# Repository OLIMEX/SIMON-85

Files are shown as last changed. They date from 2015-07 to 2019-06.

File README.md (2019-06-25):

# SIMON-85

## About
The board is an implementaion of the popular simon game which tests and trains your short-term memory. There are four LEDs, four buttons and a buzzer. The LEDs blink in random pattern which you should repeat with the buttons. Each successful guess makes the buzzer produce a sound. Each successful guess increments the amount of blinks, thus the difficulty.

The only hardware requirement for the typical use of the board is:
* USB type A to USB mini cable – to connect to a personal computer; it is used for powering the board and uploading new programs via Arduino

The board can be programmed with Digispark's Arduino distributions. Link to the download page of Digispark's Arduino distributions, suitable for Windows, Linux and MacOS: http://digistump.com/wiki/digispark/tutorials/connecting

The initial bootloader firmware can be uploaded with any combination of third party programming tool and programming software that are compatible with ATTiny85.

The binaries are suitable only for SIMON-85 board.

## How to upload binaries:

### AVR/Atmel studio
Use AVR/Atmel Studio or AVRDude to upload respectivley the .elf or the .hex to the target ATtiny85.
The .elf file contains the proper fuses and configuration bits. If you use the .hex you would need to set the fuses manually.

***It is always recommended to use the latest .hex or the latest .elf!***

## avrdude
If you use AVRDude then you need to pass the fuse settings as command line:

    avrdude -c avrispmkII -p attiny85 -U lfuse:w:0xE1:m -U hfuse:w:0xDD:m -U efuse:w:0xFE:m

If you use another programmer change ***avrispmkII*** e.g. ****stk500v2****:

    avrdude -c stk500v2 -P com26 -p attiny85 -U flash:w:<latest_version>.hex -U lfuse:w:0xE1:m -U hfuse:w:0xDD:m -U efuse:w:0xFE:m

## About the ATtiny85 fuses

Fuse name  |HEX value|Description
-----------|---------|-----------
EXTENDED|0xFE|SELFPROGEN - checked
HIGH|0xDD|Brown-out detection at VCC=2.7 V; the rest of the fuses unchecked
LOW|0xE1|PLL Clock; Start-up time PWRDWN/RESET: 1K CK/14 CK + 64 ms

The core design of the board is similar to the design of the previously released OLinuXino-85 and FOSDEM-85 boards. This might be helpful in your attempt to implementing additional examples.

THE DESIGN OF SIMON-85 IS BASED HEAVILY ON THE LITTLE WIRE'S DESIGN BY IHSAN KEHRIBAR AND USES MICRONUCLEUS BOOTLOADER AND DIGISTUMP'S DIGISPARK SOFTWARE. SIMON-85 WOULD NOT HAVE BEEN POSSIBLE WITHOUT THE EXISTENCE OF THESE PROJECTS.

The board is completely open software and open hardware.

Product pages:

* SIMON-85: https://www.olimex.com/Products/Duino/AVR/SIMON-85/open-source-hardware
* SIMON-85-KIT (DIY kit): https://www.olimex.com/Products/Duino/AVR/SIMON-85-KIT/open-source-hardware

## LICENSE
* Software License is GPL3
* Hardware License is Apache 2.0
* Documentation License is CC-BY-SA3.0 (https://creativecommons.org/licenses/by-sa/3.0/)

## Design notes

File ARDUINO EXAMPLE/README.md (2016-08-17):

## Simon-85 example description

The board is an implementation of the popular simon game which tests and trains your short-term memory.
There are four LEDs and four buttons. The LEDs blink in random pattern which you should repeat with the buttons.
Each successful guess increments the amount of blinks.

There are 4 levels of difficulties that can be selected.

### To select the level
After the board has been powered on (be patient, there is definite timeout) and the four leds are blinking consecutively, you must press and hold any button from BUT1 to BUT4. The number of the button corresponds directly to the level's number.

***That's all! Enjoy the game!***

SIMON-85 is built around the well-known Little wire design. The same design is also used for the Digispark and Adafruit’s Trinket. The microcontroller comes preprogrammed with "micronucleus tiny85" that is suitable for use with the Digispark's Arduino distribution.

## Simon-85 example installation

### Hardware and software prerequisites:

#### Hardware
* 1x Simon-85
* 1x cable to connect the board and your PC
* 1x properly installed Digispark Arduino IDE with installed AVR Digistump board package

#### Software
 * The example library is archived as zip. Please extract it anywhere and point the IDE to the .ino file inside the "Simon" folder with File -> Open

#### Notes!
* To upload the program you must first select BOTH "Tools → board" as "Digispark 8mhz - NO USB (Tiny Core)" and "Tools → Programmer" to "Digispark"
* You need to click "Upload" button first, wait for the program to compile and THEN plug the board - this is because the bootloader implementation runs for the first few seconds after power up and then the user program is executed. If you plug the board before programming the bootloader won't be available and uploading will fail. Disconnect the board, click "Upload" again and then connect the board.

There are detailed instructions in the manual and the digispark's wiki pages.

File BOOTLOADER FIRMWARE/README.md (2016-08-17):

# Bootloader binaries

The binaries consist of Digispark bootloader and Simon-85 demo example.
If you use .hex file please remember to burn fuses as well.

Current bootloader version: 2.03

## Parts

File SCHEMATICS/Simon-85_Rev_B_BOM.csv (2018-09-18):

Part | Value | Device | Package | Description
BAT-3.7V | DW02S | CON2DW02S | DW02S
BUT1 | DTSM24R(12x12x10) | SW-TAKTSS | SW_TAKT12X12SS
BUT2 | DTSM24R(12x12x10) | SW-TAKTSS | SW_TAKT12X12SS
BUT3 | DTSM24R(12x12x10) | SW-TAKTSS | SW_TAKT12X12SS
BUT4 | DTSM24R(12x12x10) | SW-TAKTSS | SW_TAKT12X12SS
BUZZER | PT1240 | BUZ3 | BUZ14MM
C1 | 10uF/16V/105C(5x11mm,RM2) | CPOL-EUE2-5_BOT | E2-5_B | POLARIZED CAPACITOR, European symbol
C2 | 100nF/2010 | C-EU025-025X050 | C025-025X050 | CAPACITOR, European symbol
C3 | 100nF/2010 | C-EU025-025X050 | C025-025X050 | CAPACITOR, European symbol
D1 | 1N4148/DO35 | DDO35 | DO35-200MILS | DIODES
D2 | 1N4148/DO35 | DDO35 | DO35-200MILS | DIODES
D3 | 1N4148/DO35 | DDO35 | DO35-200MILS | DIODES
D4 | 1N4148/DO35 | DDO35 | DO35-200MILS | DIODES
D5 | 1N4148/DO35 | DDO35 | DO35-200MILS | DIODES
LED1 | LED/Green/5mm | LED5.0MM | LED-5.0MM
LED2 | LED/Red/5mm | LED5.0MM | LED-5.0MM
LED3 | LED/White/5mm | LED5.0MM | LED-5.0MM
LED4 | LED/Blue/5mm | LED5.0MM | LED-5.0MM
R1 | 10k/0.25W | R-EU_0207/10 | 0207/10 | RESISTOR, European symbol
R2 | 3.9k/0.25W | R-EU_0207/10 | 0207/10 | RESISTOR, European symbol
R3 | 22R/0.25W | R-EU_0207/10 | 0207/10 | RESISTOR, European symbol
R4 | 22R/0.25W | R-EU_0207/10 | 0207/10 | RESISTOR, European symbol
R5 | 560R/0.25W | R-EU_0207/10 | 0207/10 | RESISTOR, European symbol
R6 | 2k/0.25W | R-EU_0207/10 | 0207/10 | RESISTOR, European symbol
R7 | 560R/0.25W | R-EU_0207/10 | 0207/10 | RESISTOR, European symbol
R8 | 560R/0.25W | R-EU_0207/10 | 0207/10 | RESISTOR, European symbol
R9 | 560R/0.25W | R-EU_0207/10 | 0207/10 | RESISTOR, European symbol
R10 | 560R/0.25W | R-EU_0207/10 | 0207/10 | RESISTOR, European symbol
R11 | 560R/0.25W | R-EU_0207/10 | 0207/10 | RESISTOR, European symbol
R12 | 560R/0.25W | R-EU_0207/10 | 0207/10 | RESISTOR, European symbol
U1 | ATtiny85-20PU+(DIL-8) | ATTINY85-20PU | DIP8 | Atmel 8-bit AVR Microcontroller with 2/4/8K Bytes In-System Programmable Flash
USB | USB-B | USB_SHIELD | USB_NEAR_BLACK

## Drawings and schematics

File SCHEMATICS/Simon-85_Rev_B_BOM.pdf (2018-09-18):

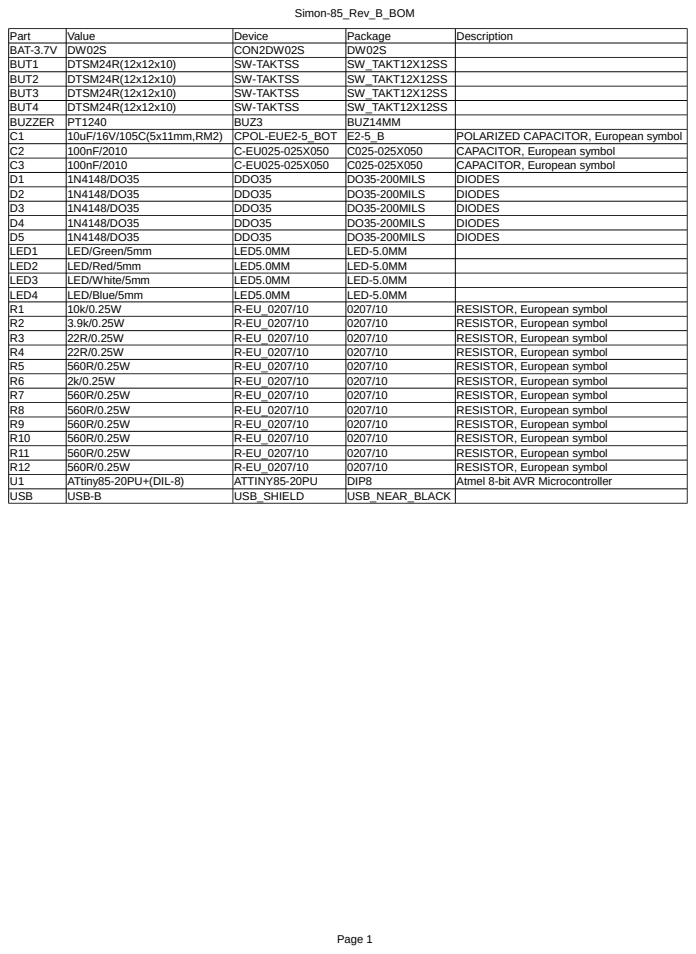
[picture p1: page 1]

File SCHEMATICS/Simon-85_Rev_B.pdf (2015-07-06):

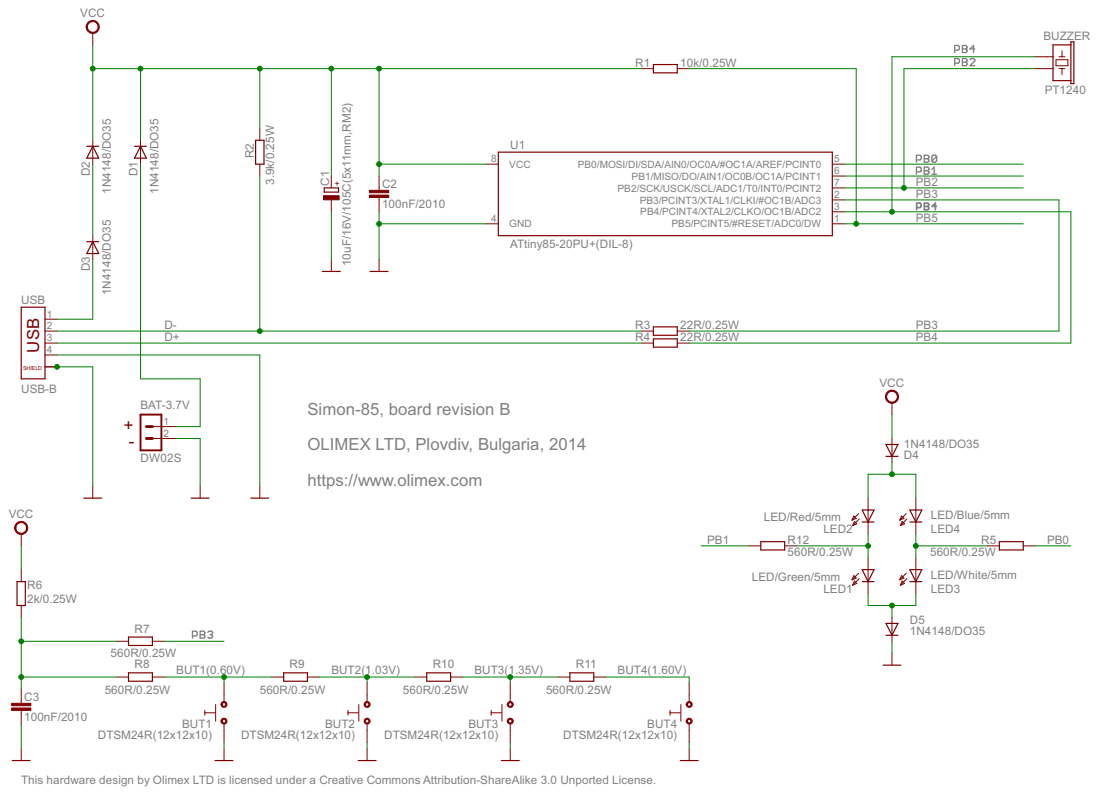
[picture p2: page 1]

6 PB0/MOSI/DI/SDA/AIN0/OC0A/#OC1A/AREF/PCINT0

OLIMEX LTD, Plovdiv, Bulgaria, 2014

https://www.olimex.com

This hardware design by Olimex LTD is licensed under a Creative Commons Attribution-ShareAlike 3.0 Unported License.

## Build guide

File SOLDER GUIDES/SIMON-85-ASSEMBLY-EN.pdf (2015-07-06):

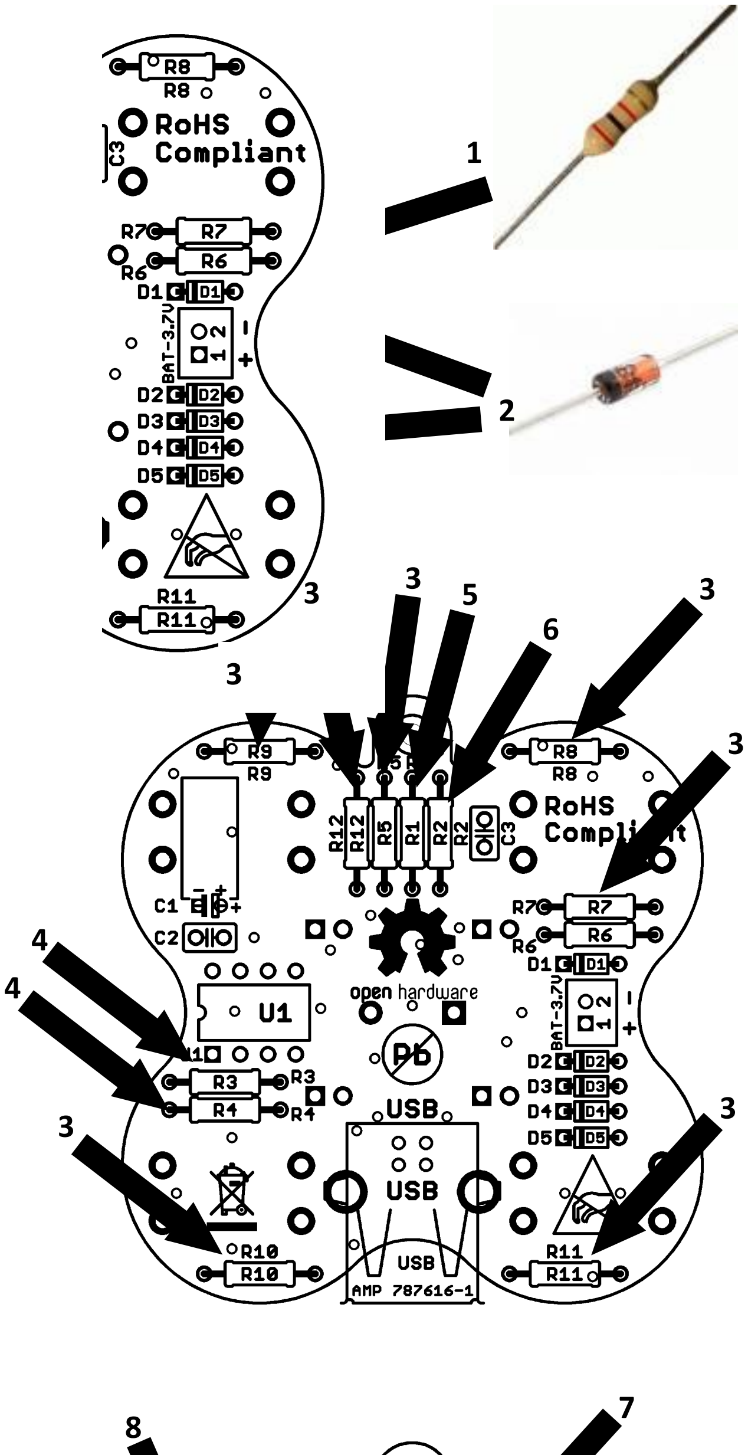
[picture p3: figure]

1. A 2K ohm resistor (red, black, red, golden) position R6.
2. 5 x Diodes 1N4148 positions D1, D2, D3, D4, and D5. Watch out for the orientation. The stripe of the diode has to be oriented as indicated by the white print on the board.
3. 7 x 560 ohm resistors (green, blue, brown, gold) at positions R5, R7, R8, R9, R10, R11, R12.
4. 2 x 22 ohm resistors (red, red, black, gold) at positions R3 and R4.
5. A 10k ohm resistor (brown, black, orange, gold) at position R1.
6. A 3.9K ohm resistor (orange, white, red, gold) at position R2.
7. 2 x capacitors 100nF (code 104) at positions C2 and C3.

### 8. An electrolytic capacitor 10μF at position C1. The

component has polarity! The short pin is negative (-), the long pin is positive (+). Place it in the holes and leave some space between the capacitor and the board. Bend the pins to lie horizontally (e.g. flat) on the board. Then proceed to solder it.

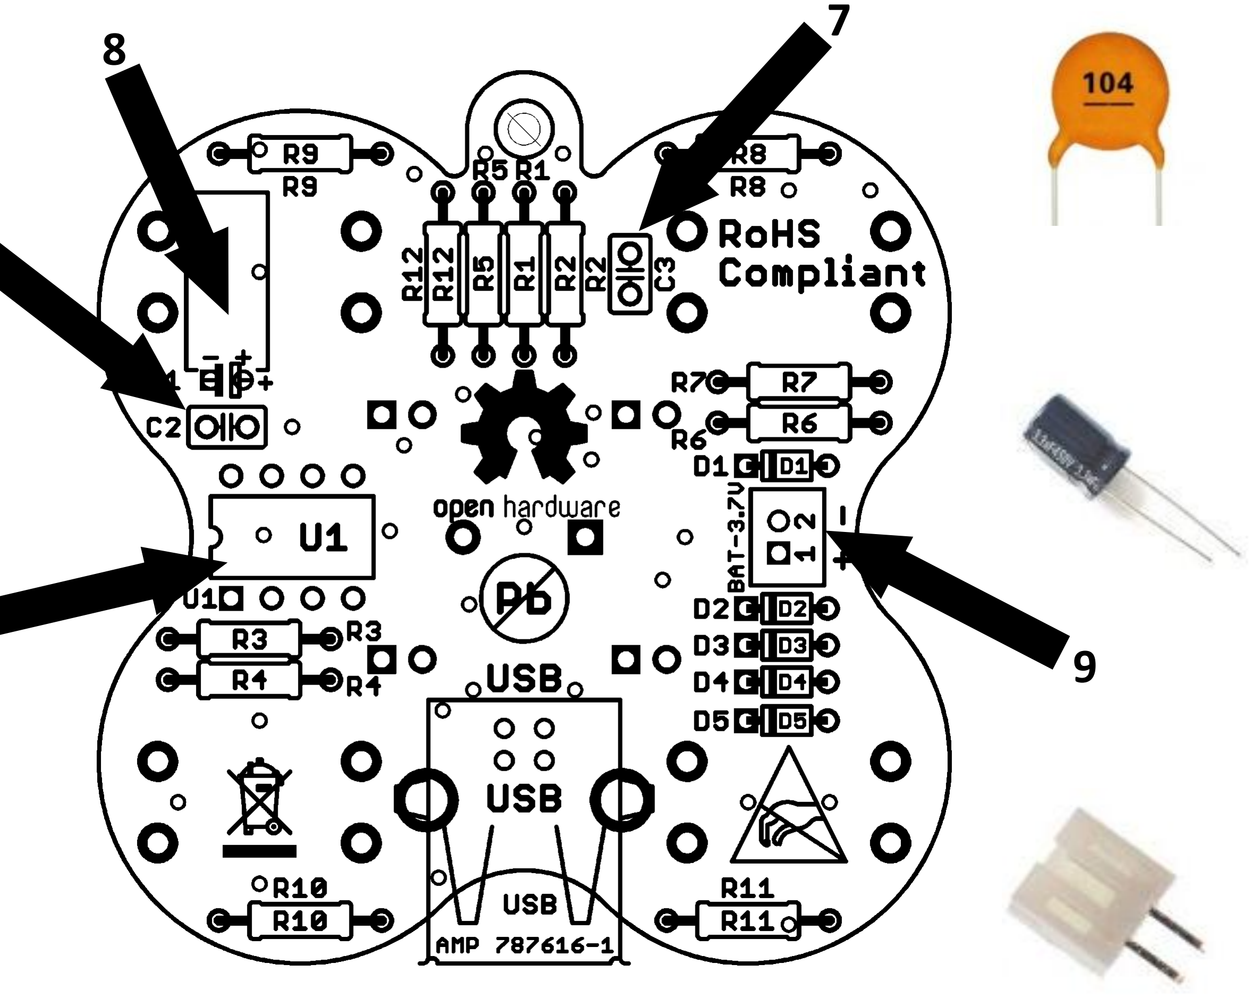
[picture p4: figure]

### 10. An 8-pin DIL socket at position U1. Be careful! The microcontroller may overheat

during prolonged soldering. It is recommended to remove the ATtiny85 from the socket before soldering. Watch out for the socket orientation! The socket has a dent that should be facing outwards of the board.

### 9. A connector DW02S. Be careful with the

orientation. The gap in the connector must be facing towards the middle of the board!

7

10

SIMON-85-KIT. Soldering details, order, and tips.

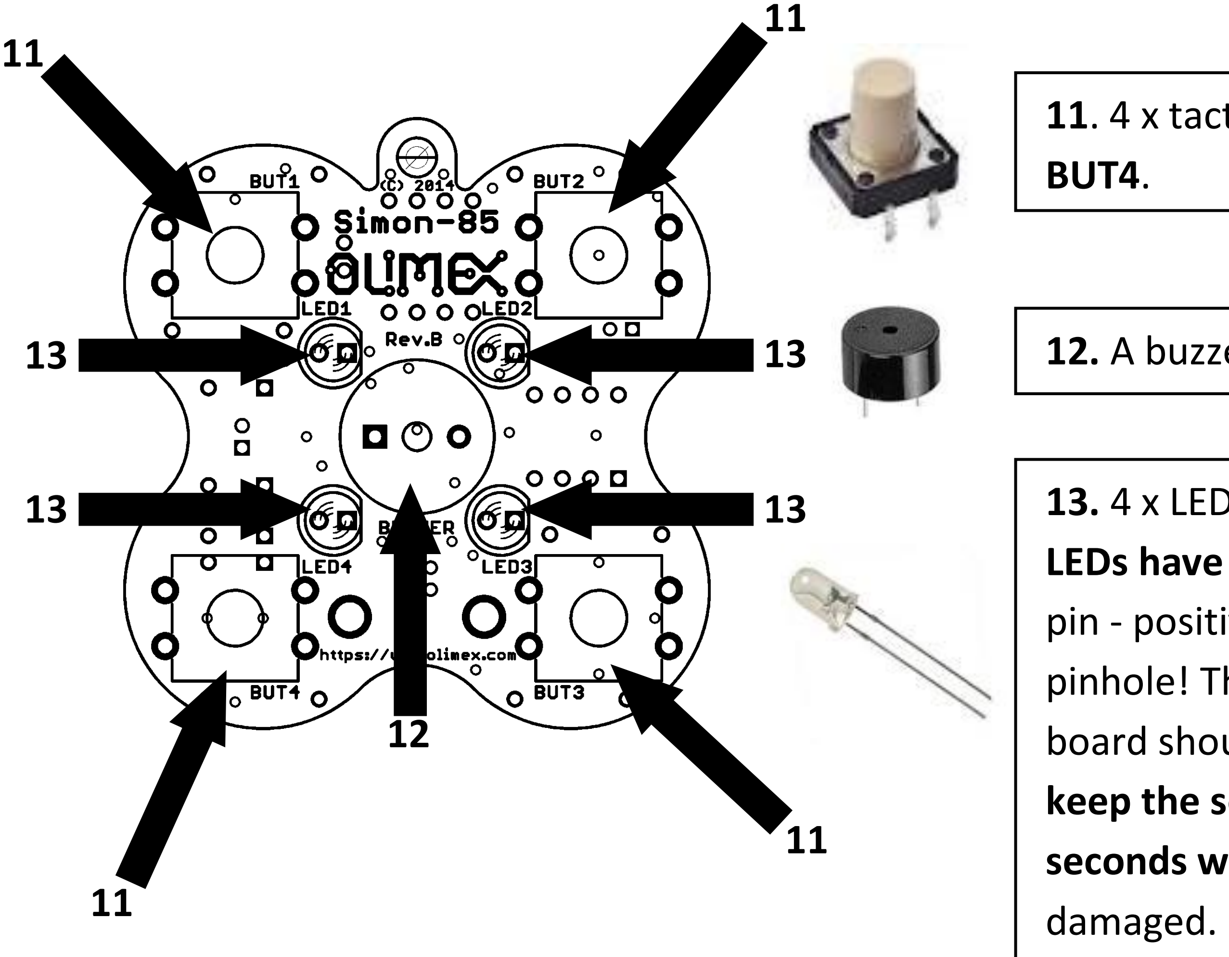
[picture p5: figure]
BUT4.; damaged.
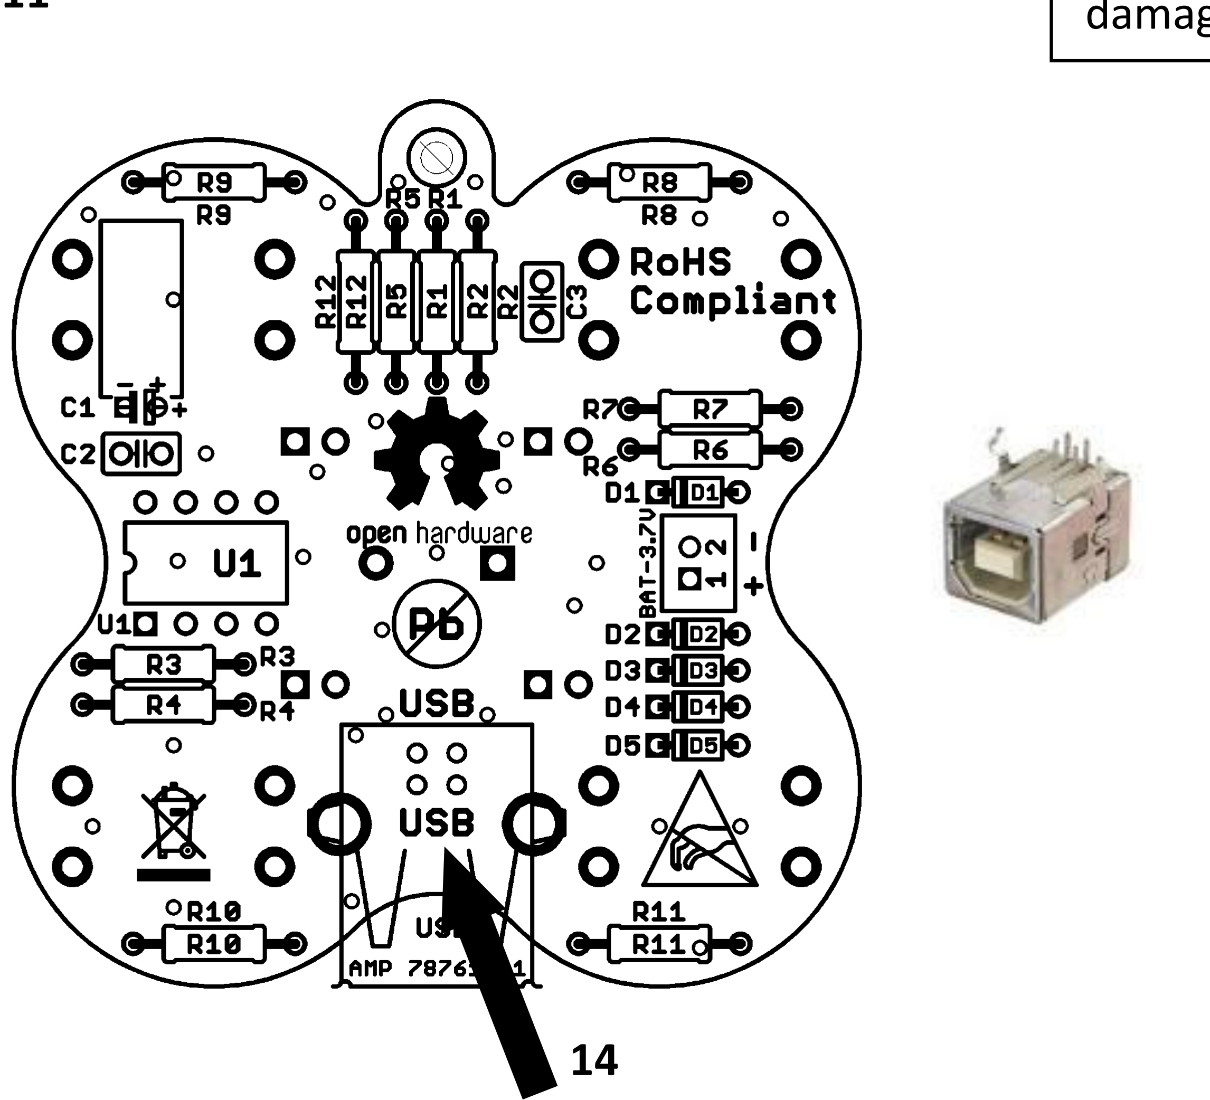
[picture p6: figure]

Turn the board and wait for about 5 seconds. Then four LEDs should turn on. Check the next page for game description and available difficulties!

11. 4 x tactile buttons at positions BUT1, BUT2, BUT3, and
13. 4 x LEDs at positions LED1, LED2, LED3, and LED4. LEDs have polarity! The short pin is negative (-), the long pin - positive (+). The negative pin goes to the square pinhole! The flat line vsible on the white print of the board should match the flat side of the diode. Do not keep the soldering iron pressed for more than 2-3 seconds when soldering. Else the LED might get

### 14. A USB type B connector at position USB. The

connector is placed at the same side of the board as the microcontroller! Double check for short-circuits between the pins before powering!

12. A buzzer at position BUZZER.

### 15. After successful assembly of all other components – place the ATtiny85

microcontroller in the U1 DIL-8 socket. Be careful with the orientation. The microcontroller has a dot, which indicates the first pin. The dot should be facing outwards the board.

=== SIMON-85 default game description ===

The board is an implementation of the popular simon game which tests and trains your short-term memory.

The board gets powered by a USB cable compatible with the board’s USB type B connector. You need to wait at least 5 seconds after the board gets powered.

There are four LEDs and four buttons. A number of LEDs blink in a random pattern which you should repeat with the buttons. Each successful guess increments the amount of blinks that you would need to guess. If you make an erroneous button press the game would restart.

The buzzer sounds would help you remember the patterns. There is a victory song If manage to complete the game.

There are 4 levels of difficulties that can be selected.

Level 1 -> 10 repetitions

Level 2 -> 20 repetitions

Level 3 -> 30 repetitions

Level 4 -> 40 repetitions

To select the difficulty level: after the board had been powered on (be patient, there is timeout defined on purpose) and the four leds are blinking consecutively, you must press and hold any button from BUT1 to BUT4. The number of the button corresponds directly to the level's number.

That's all! Enjoy the game!

For additional resources (sources and schematics) please visit the products web-page at Olimex web-site:

https://www.olimex.com/Products/Duino/AVR/SIMON-85-KIT

The board is also available in a ready-to-use and soldered variant. For more information please visit the product’s web-page at our web-site:

https://www.olimex.com/Products/Duino/AVR/SIMON-85

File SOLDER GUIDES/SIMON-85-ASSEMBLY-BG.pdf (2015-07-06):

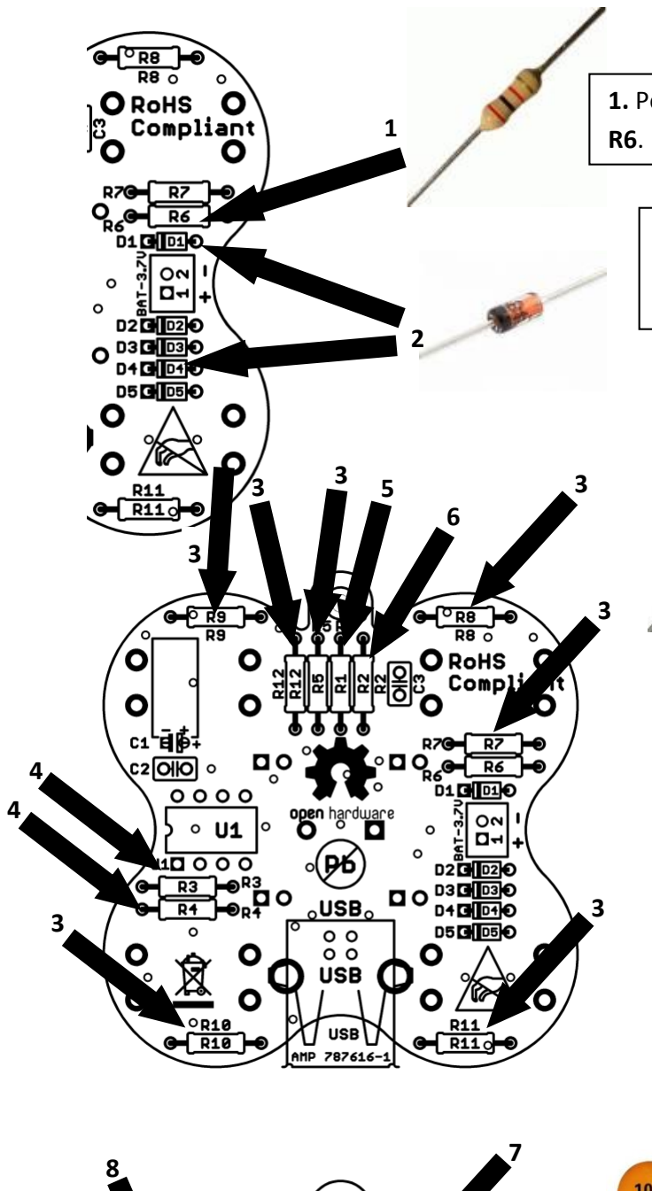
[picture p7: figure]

### 1. Резистор 2K ома (червено, черно, червено, златно) на позиция

2. Диод 1N4148 на позиции D1, D2, D3, D4 и D5. Внимавайте за ориентацията. Чертата на диода трябва да е с еднаква посока като тази на печата на платката.
3. Резистор 560 ома (зелено, синьо, кафяво, златно) на позиции R5, R7, R8, R9, R10, R11, R12.
4. Резистор 22 ома (червено, червено, черно, златно) на позиции R3 и R4.
5. Резистор 10k ома (кафяво, черно, оранжево, златно) на позиция R1.
6. Резистор 3,9k ома (оранжево, бяло, червено, златно) на позиция R2.

### 7. Кондензатор 100nF (код 104) на позиции C2 и

C3.

8. Електролитен кондензатор 10µF на позиция C1. Този елемент е полярен. Късият крак е минус (-), а дългият – плюс (+). Сложете го в дупките, като оставите малко място между него и платката. Извийте краката му за да легне хоризонтално на платката. След това пристъпете към запояване.

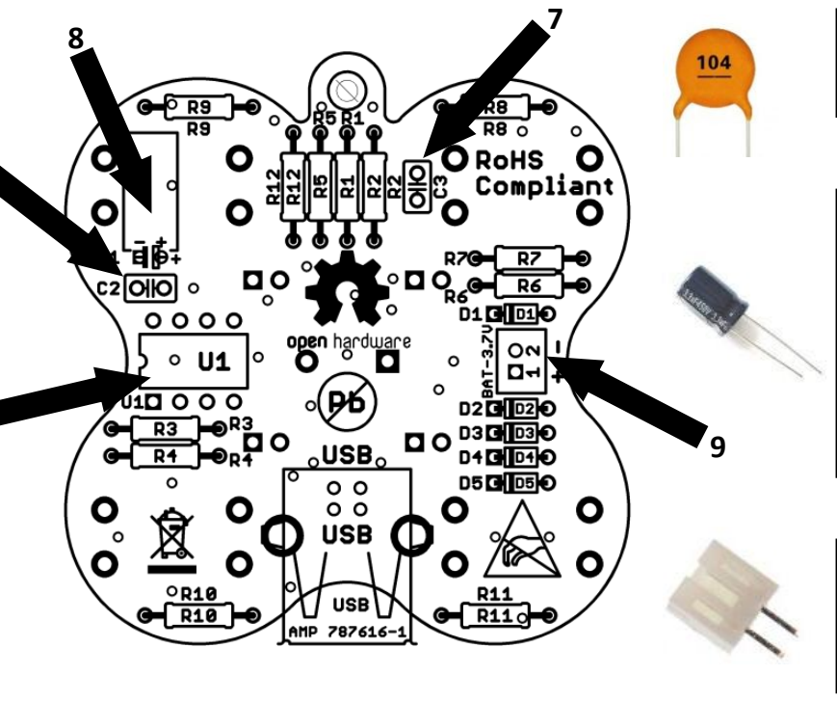
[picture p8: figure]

### 10. Цокъл с микроконтролер на позиция U1. Бъдете предпазливи! Чипът може да се

повреди от прегряване! Препоръчително е да го монтирате, като предварително извадите чипът от него. Внимавайте за ориентацията! От едната страна на цокъла има канал. То трябва да сочи навън от платката!

### 9. Конектор DW02S. Внимавайте с посоката на

запояване! Цепката на конектора трябва да е насочена към средата на платката!

7

10

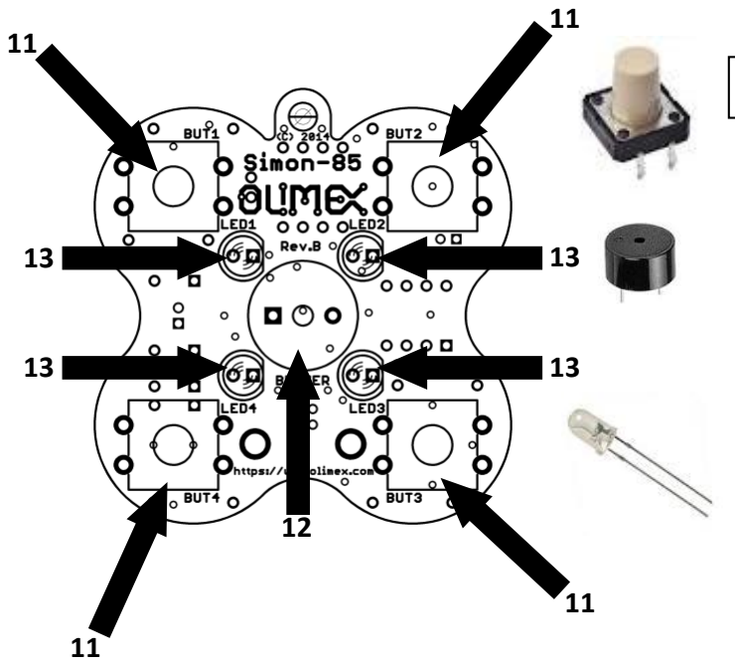
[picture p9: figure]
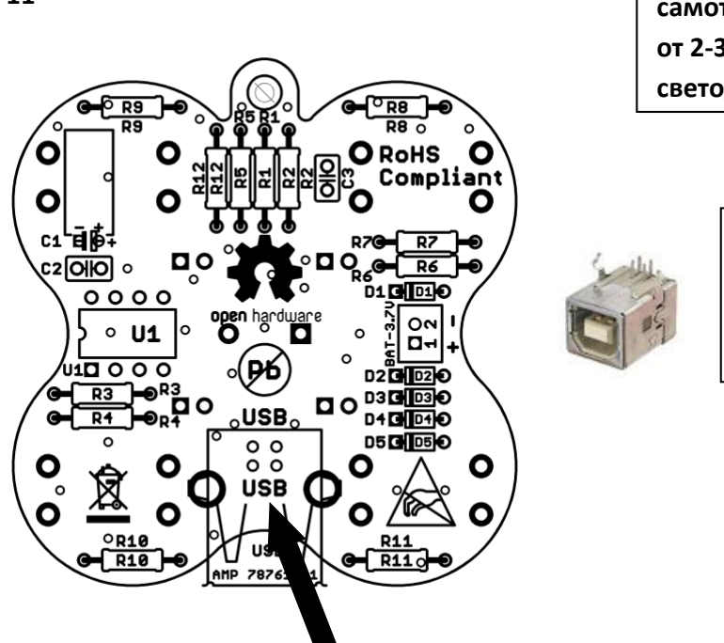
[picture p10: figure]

Включете платката и изчакайте около 5 секунди. След това четирите светодиода трябва да мигат в кръг.

Описание на играта:

При стартиране светодиодите светят в кръг. Натиснете и задръжте някой от бутоните, като това ще определи нивото на трудност. За първо ниво(10 повторения) – BUT1, второ(20 повторения) - BUT2, трето(30 повторения) – BUT3 и за четвърто(40 повторения) – BUT4. Пуснете бутона и изчакайте мелодията, оказваща начало на играта. Една секунда след края на мелодията произволен светодиод ще премигне. Натиснете бутона съответстващ на него. След това ще премигне същият светодиод и още един произволен. Следващият път първите два и още един произволен и т.н. Броя на потворенията, които трябва да направите зависи от трудността. При грешка играта се връща в изходна позиция.

За допълнителни ресурси: https://www.olimex.com/Products/Duino/AVR/SIMON-85

11. Тактов бутон на позиции BUT1, BUT2, BUT3 и BUT4.
13. Светодиод на позиции LED1, LED2, LED3 и LED4. Светодиодите са полярни елементи! Късият крак е катод(-), а дългият – анод(+). Катодът трябва да се постави в квадратната площадка! Друг ориентир е също и скосената страна на печата – към него трябва пак да сочи катодът! Тя също трябва да съвпада със скосената такава на корпуса на светодиода. При самото запояване не задържайте поялника по-дълго от 2-3 секунди. В противен случай може да стопите светодиода!
14. USB B конектор на позиция USB. Конекторът се поставя от страната на микроконтролера. При монтиране се уверете, че няма късо между запоените крака!
12. Бъзер на позиция BUZZER.
15. След успешното монтиране на всички елементи поставете чипа върху цокъла. Внимавайте за ориентацията! На единия край на чипа има точка. Тя показва мястото на първи крак на корпуса. Точката трябва е насочена към ръба на платката!

14

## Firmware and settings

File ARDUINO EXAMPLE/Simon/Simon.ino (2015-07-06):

/*

  Extension to read from the buttons

    Copyright (C) 2014  Stefan Mavrodiev @ OLIMEX LTD

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
    You should have received a copy of the GNU General Public License
    along with this program.  If not, see <http://www.gnu.org/licenses/>.
*/

#include "music.h"
#include "leds.h"
#include "button.h"

/* If you want to disable buzzer uncomment the following line */
//#define NO_SOUND

uint8_t randomArray[60];
uint8_t maxItem = 60;
uint8_t difficulty = 1;


void generateRandom(){
  for(int i = 0; i < sizeof(randomArray)/sizeof(uint8_t); i++){
    randomArray[i] = random(1, 5);
  }
}

void resetGame(){  

  digitalWrite(2, LOW);
  digitalWrite(4, LOW);

  pinMode(2, INPUT);
  pinMode(4, INPUT);
  delay(1);

  randomSeed(analogRead(1));
  generateRandom();

  pinMode(2, OUTPUT);
  pinMode(4, OUTPUT);

#ifndef NO_SOUND
  playTune();
#endif
}

void waitForStart(){
  int but;
  while(1){
    for(int i = 1; i < 5; i++){
      clearLeds();
      setLed(i);
      delay(100);
    }
    but = debounceButton();
    if(but != 0){
      maxItem = but*10;
      difficulty = but;
      clearLeds();
      setLed(but);
      break;
    }
    
  }
  while(debounceButton() != 0);
  clearLeds();
  
  
  
}


void startGame(){
  for(int i = 0; i < maxItem; i++){
    for(int j = 0; j < i+1; j++){
      setLed(randomArray[j]);
#ifndef NO_SOUND
      soundBuzzer(randomArray[j]);
#endif
      delay(200/difficulty);
      clearLeds();
      delay(200/difficulty);
    }
    for(int j = 0; j < i+1; j++){
      int but;
      while(debounceButton() != 0);
      do{
        but = debounceButton();
      }while(but == 0);
      setLed(but);
#ifndef NO_SOUND
      soundBuzzer(but);
#endif
      while(debounceButton() != 0);
      clearLeds();

      if(but != randomArray[j]){
#ifndef NO_SOUND
        playGameOver();
#endif
        return;
      }
    }
    delay(500);
  }
#ifndef NO_SOUND
  playWin();
#endif
}



void setup() {

  pinMode(0, INPUT);    // led3 and led4
  pinMode(1, INPUT);    // led1 and led 2
  pinMode(3, INPUT);    // ADC
  pinMode(2, OUTPUT);
  pinMode(4, OUTPUT);

}

void loop() {

  waitForStart();
  delay(1000);
  resetGame();
  delay(1000);
  startGame();
}

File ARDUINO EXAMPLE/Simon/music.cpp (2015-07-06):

/*

  Extension to make music with buzzer

    Copyright (C) 2014  Stefan Mavrodiev @ OLIMEX LTD

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
    You should have received a copy of the GNU General Public License
    along with this program.  If not, see <http://www.gnu.org/licenses/>.
*/

#include "music.h"
#include "notes.h"
#include "leds.h"

void playNote(uint16_t note, uint16_t duration){

  setLed((note % 4)+1);
  uint32_t beginMilis = millis();

  if(!note){
    // if note is 0 this means it is rest. Just do nothing
    while(millis() - beginMilis < duration);
  }else{
    // sound the buzzer with given frequency.
    do{

      digitalWrite(2, HIGH);
      digitalWrite(4, LOW);
      delayMicroseconds(note);

      digitalWrite(2, LOW);
      digitalWrite(4, HIGH);
      delayMicroseconds(note);

    }while(millis() - beginMilis < duration);
  }
  clearLeds();
  delay(1);
    
}

void playNoteNoLed(uint16_t note, uint16_t duration){

  uint32_t beginMilis = millis();

  if(!note){
    // if note is 0 this means it is rest. Just do nothing
    while(millis() - beginMilis < duration);
  }else{
    // sound the buzzer with given frequency.
    do{

      digitalWrite(2, HIGH);
      digitalWrite(4, LOW);
      delayMicroseconds(note);

      digitalWrite(2, LOW);
      digitalWrite(4, HIGH);
      delayMicroseconds(note);

    }while(millis() - beginMilis < duration);
  }
  delay(1);

}


void playLongNote(uint16_t note, uint16_t duration){
  playNote(note, duration);
  playNote(note, duration/2);
}
void playStaccatoNote(uint16_t note, uint16_t duration){
  playNote(note, STACCATO_NOTE(duration));
  delay(STACCATO_NOTE(duration));
}

void playTriplets(uint16_t note1, uint16_t note2, uint16_t note3, uint16_t duration){
  uint16_t dur = duration;
  dur = duration/3;
  playNote(note1, dur);
  playNote(note2, dur);
  playNote(note3, dur);
}

void playTune(){
    
  // this is Super Mario Bros. theme :)
  playStaccatoNote(E5, EIGHTH_NOTE);
  playStaccatoNote(E5, EIGHTH_NOTE);
  playNote(REST, EIGHTH_NOTE);
  playStaccatoNote(E5, EIGHTH_NOTE);

  playNote(REST, EIGHTH_NOTE);
  playStaccatoNote(C5, EIGHTH_NOTE);
  playStaccatoNote(E5, EIGHTH_NOTE);
  playNote(REST, EIGHTH_NOTE);

  playStaccatoNote(G5, QUARTER_NOTE);
  playNote(REST, QUARTER_NOTE);
  playStaccatoNote(G4, QUARTER_NOTE);
  playNote(REST, QUARTER_NOTE);

}

void soundBuzzer(uint8_t led){
  switch(led){
    case 0x01:
      playNoteNoLed(C5, EIGHTH_NOTE);
      break;

    case 0x02:
      playNoteNoLed(D5, EIGHTH_NOTE);
      break;

    case 0x03:
      playNoteNoLed(E5, EIGHTH_NOTE);
      break;

    case 0x04:
      playNoteNoLed(F5, EIGHTH_NOTE);
      break;

    default:
      break;
  }
}

void playWin(void){


  playStaccatoNote(A4, EIGHTH_NOTE*2);
  playNote(REST, EIGHTH_NOTE*2);
  playLongNote(C4, EIGHTH_NOTE*2);
  playStaccatoNote(A4, EIGHTH_NOTE*2);
  playStaccatoNote(A4, SIXTEEN_NOTE*2);
  playNote(D4, EIGHTH_NOTE*2);
  playNote(A4, EIGHTH_NOTE*2);
  playStaccatoNote(G4, EIGHTH_NOTE*2);
  
  playNote(A4, EIGHTH_NOTE*2);
  playNote(REST, EIGHTH_NOTE*2);  
  playLongNote(E4, EIGHTH_NOTE*2);
  playStaccatoNote(A4, EIGHTH_NOTE*2);
  playStaccatoNote(A4, SIXTEEN_NOTE*2);
  playStaccatoNote(F4, EIGHTH_NOTE*2);
  playStaccatoNote(E4, EIGHTH_NOTE*2);
  playStaccatoNote(C4, EIGHTH_NOTE*2);
  playStaccatoNote(A4, EIGHTH_NOTE*2);
  playStaccatoNote(E4, EIGHTH_NOTE*2);
  playStaccatoNote(A5, EIGHTH_NOTE*2);
  playStaccatoNote(A4, SIXTEEN_NOTE*2);
  playStaccatoNote(G3, EIGHTH_NOTE*2);
  playStaccatoNote(G3, SIXTEEN_NOTE*2);
  playStaccatoNote(E3, EIGHTH_NOTE*2);
  playStaccatoNote(B4, EIGHTH_NOTE*2);
  playLongNote(A4, QUARTER_NOTE*2);

  
}
void playGameOver(void){
  playTriplets(REST, REST, REST, HALF_NOTE);
  playTriplets(E4, Db4, E4, HALF_NOTE);
  playTriplets(Eb4, C4, Eb4, HALF_NOTE);
  playTriplets(D4, B4, D4, HALF_NOTE);
  playStaccatoNote(Db4, QUARTER_NOTE);
  playStaccatoNote(D3, QUARTER_NOTE);
  playStaccatoNote(Eb3, QUARTER_NOTE);
  playNote(E3, HALF_NOTE);
}

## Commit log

2015-10-05 Bootloader update
    Updated bootloader to micronucleus 1.11; fixes battery start-up issues.
2018-09-18 Update
    Gerbers and BoMs
    [Simon-85_Rev_B_BOM.csv, Simon-85_Rev_B_BOM.ods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]

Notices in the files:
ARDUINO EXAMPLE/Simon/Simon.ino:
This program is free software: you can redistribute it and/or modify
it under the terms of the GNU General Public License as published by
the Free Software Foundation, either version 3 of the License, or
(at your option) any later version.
